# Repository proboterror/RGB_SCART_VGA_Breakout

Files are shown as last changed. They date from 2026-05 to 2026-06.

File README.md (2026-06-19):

# RGB SCART / VGA Breakout

For RGB/SCART modding JVC, SONY PVM video monitors and consumer CRT TVs.

Mounting holes step 10 mm, matching JVC monitors case.

Continuation of [RGB SCART Breakout board](https://github.com/proboterror/RGB_SCART_Breakout).

Features:
- SCART / VGA inputs are not switchable. Simultaneous connection are NOT RECOMMENDED, use at own risk.
- Protection diodes on SCART Blanking / VGA +5V inputs against back current with 2 devices connected.
- Sync 75 Ohm load bypass option.
- 3.5 mm mini jack connector for SCART input.

## Schematics:<br>
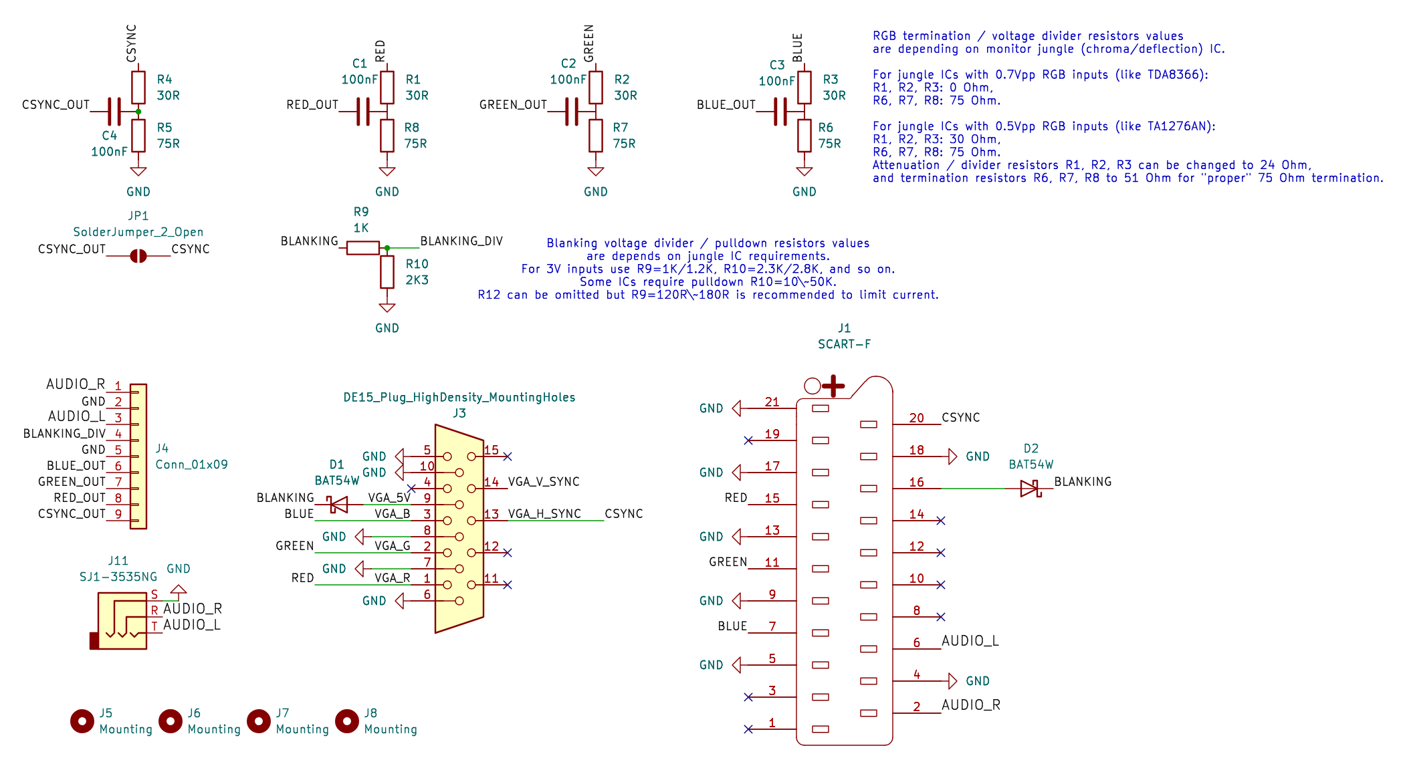
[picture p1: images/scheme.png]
Scheme


## Board view:<br>
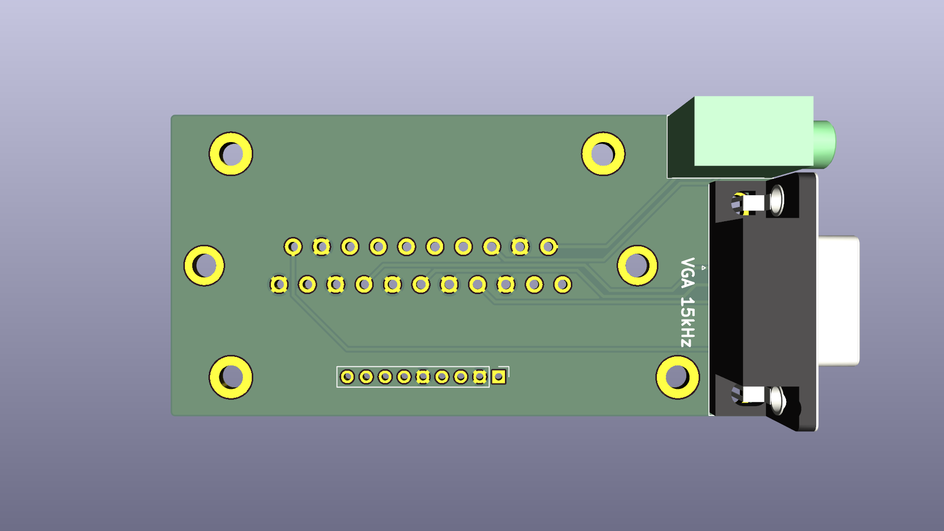
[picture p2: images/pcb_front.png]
Front

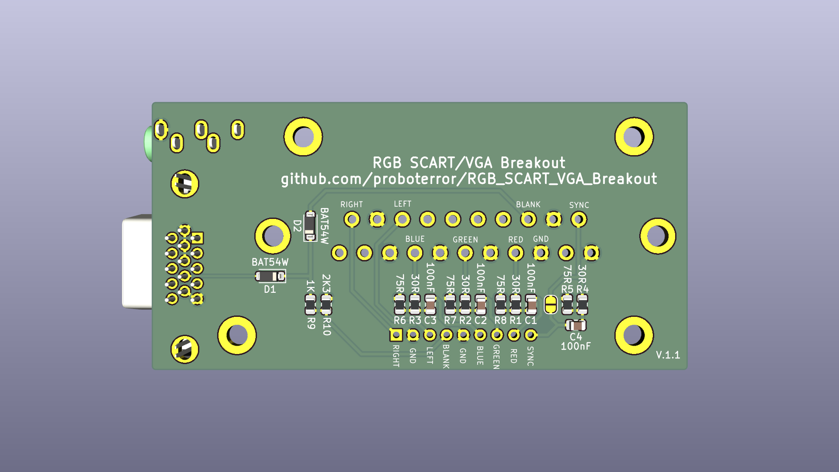
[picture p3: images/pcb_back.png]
Back

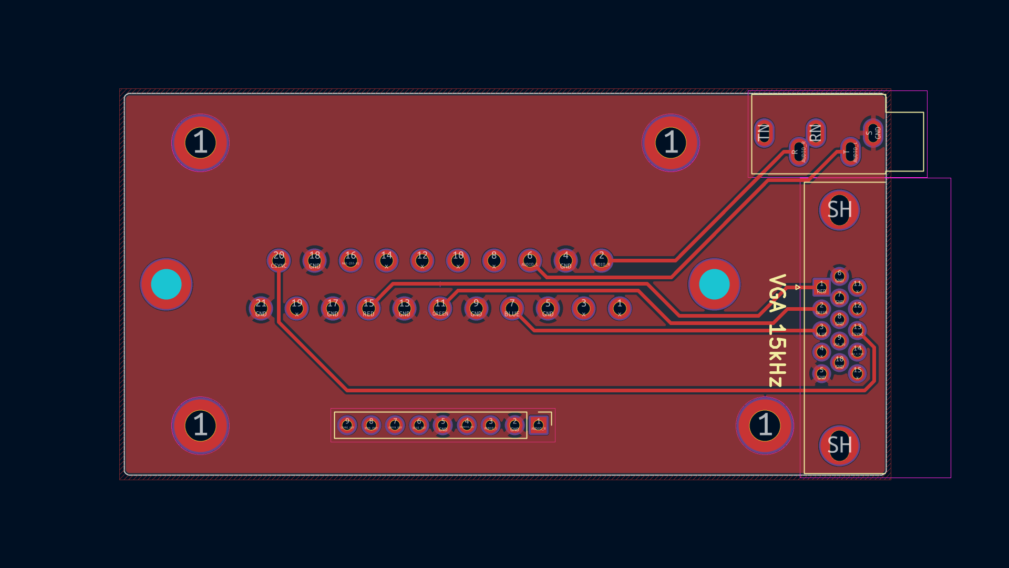
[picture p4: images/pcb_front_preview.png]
Front preview

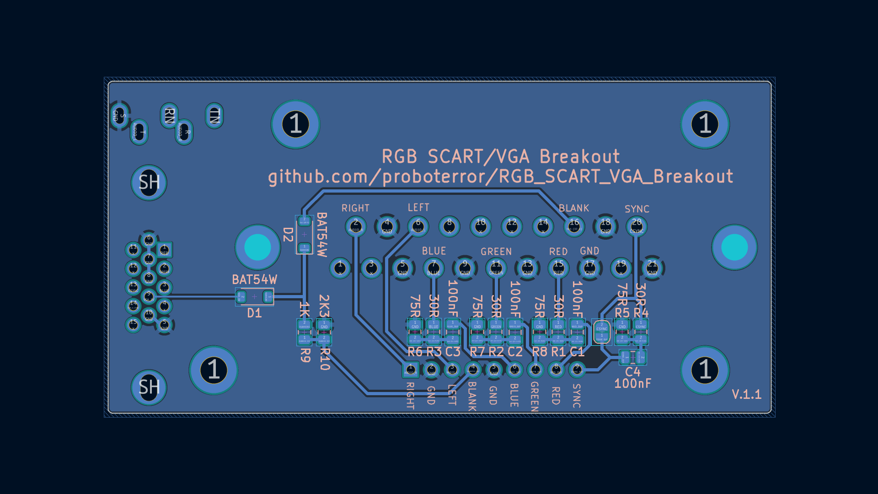
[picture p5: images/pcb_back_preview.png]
Back preview

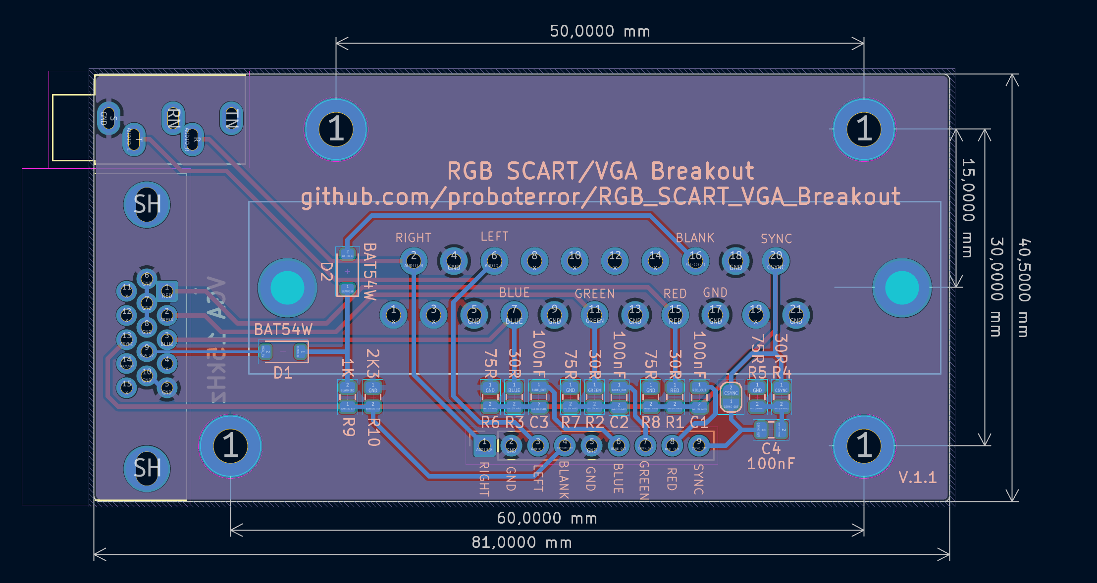
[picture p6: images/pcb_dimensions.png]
PCB dimensions


## Bill of Materials
|Reference|Value|Footprint|Qty|
|-----|-----|-----|-----|
|C1,C2,C3,C4|100nF|0805|4|
|D1,D2|BAT54W|Diode_SMD:D_SOD-123|2|
|J1|SCART-F|CS-102 (SCART-21S)|1|
|J3|DE15 Socket / DSUB-15-HD / VGA| DSUB-15-HD_Socket_Horizontal P2.29x1.90mm EdgePinOffset3.03mm MountingHolesOffset4.94mm|1|
|J11|SJ1-3535NG|CUI/Same Sky Device SJ1-3535NG|1|
|R1,R2,R3,R4|0R/24R/30R|0805|4|
|R5,R6,R7,R8|75R/51R|0805|4|
|R9|1K/1K2/4K7|0805|1|
|R10|2.3K/2K8/10K|0805|1|

Notes:
- All resistors are 1%.
- RGB termination / voltage divider resistors values are depending on monitor jungle (chroma/deflection) IC.<br>
For jungle ICs with 0.7Vpp RGB inputs (like TDA8366):<br>
R1, R2, R3: 0 Ohm,<br>
R6, R7, R8: 75 Ohm.<br>
For jungle ICs with 0.5Vpp RGB inputs (like TA1276AN):<br>
R1, R2, R3: 30 Ohm,<br>
R6, R7, R8: 75 Ohm.<br>
Attenuation / divider resistors R1, R2, R3 can be changed to 24 Ohm, and termination resistors R6, R7, R8 to 51 Ohm for "proper" 75 Ohm termination.
- Blanking voltage divider / pulldown resistors values are depends on jungle IC requirements.<br>
For 3V inputs use R9=1K/1.2K, R10=2.3K/2.8K, and so on.<br>
Some ICs require pulldown R10=10\~50K.<br>
R12 can be omitted but R9=120R\~180R is recommended to limit current.
- More info on Blanking voltage divider: [sector.sunthar.com/guides/crt-rgb-mod](https://sector.sunthar.com/guides/crt-rgb-mod/rgb-mux.html#how-to-use-the-voltage-divider-on-the-board)

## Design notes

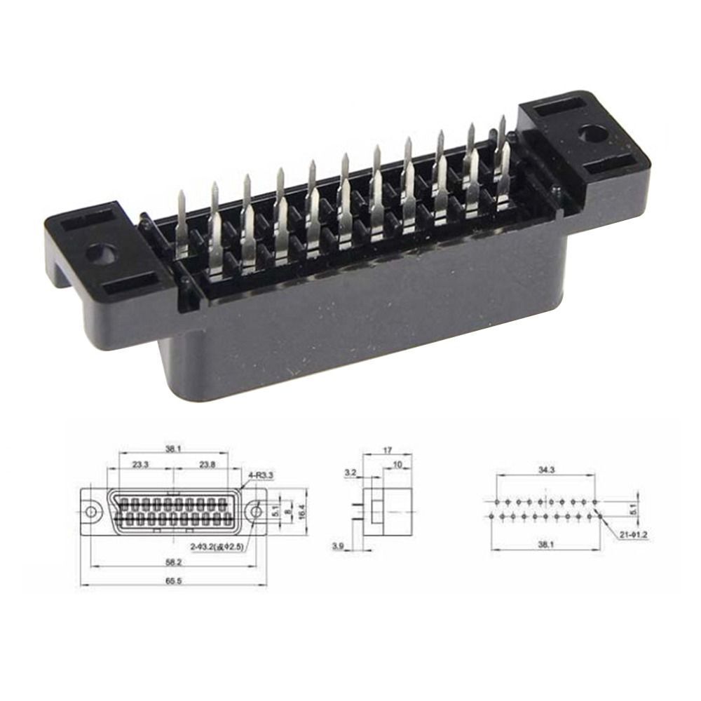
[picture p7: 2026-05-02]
datasheets/SCART_21_PIN_VERTICAL.jpg

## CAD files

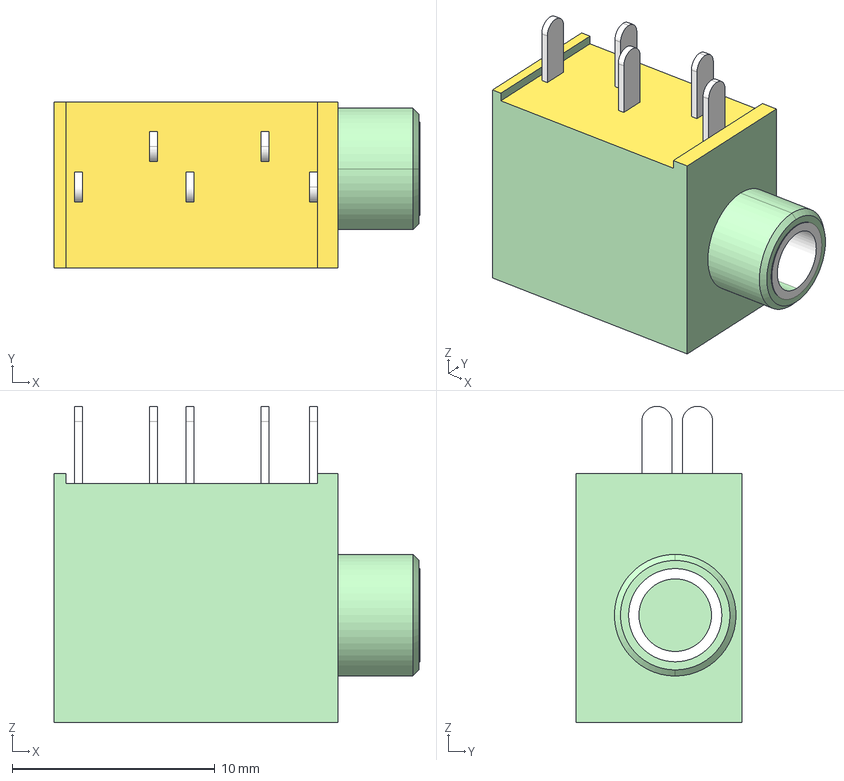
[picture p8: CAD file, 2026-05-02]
KiCad/3dshapes/CUI_DEVICES_SJ1-3535NG-G.step
18.1 x 8.20 x 15.6 mm

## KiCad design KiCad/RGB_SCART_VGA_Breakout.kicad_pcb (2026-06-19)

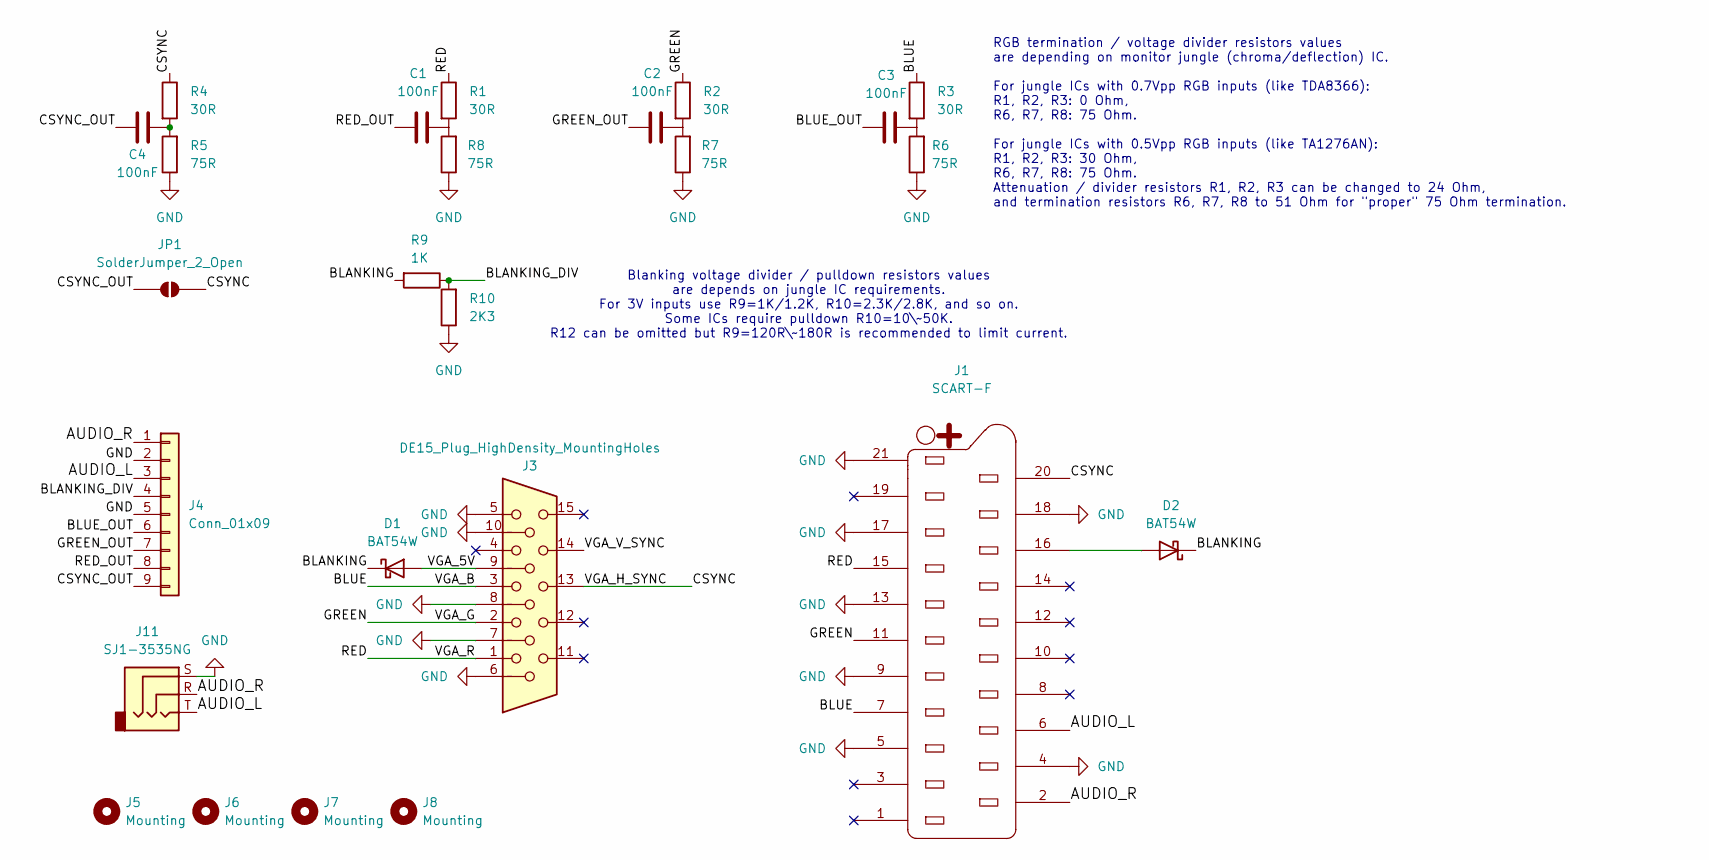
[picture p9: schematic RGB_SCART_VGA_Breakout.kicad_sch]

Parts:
C1, C2, C3, C4: 100nF; C_0805_2012Metric
D1, D2: BAT54W; D_SOD-123
J1: SCART-F; K-SCARTX-024
J3: DE15_Plug_HighDensity_MountingHoles; DSUB-15-HD_Socket_Horizontal_P2.29x1.90mm_EdgePinOffset3.03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
J4: Conn_01x09; PinHeader_1x09_P2.54mm_Vertical
J5, J6, J7, J8: Mounting; MountingHole_3.2mm_M3_DIN965_Pad
J11: SJ1-3535NG; Jack_3.5mm_CUI_SJ1-3535NG_Horizontal
JP1: SolderJumper_2_Open; SolderJumper-2_P1.3mm_Open_RoundedPad1.0x1.5mm
R1, R2, R3, R4: 30R; R_0805_2012Metric
R5, R6, R7, R8: 75R; R_0805_2012Metric
R9: 1K; R_0805_2012Metric
R10: 2K3; R_0805_2012Metric

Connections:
/AUDIO_L: J1.6, J4.3, J11.T
/AUDIO_R: J1.2, J4.1, J11.R
/BLANKING: D1.1 (K), D2.1 (K), R9.2
/BLANKING_DIV: J4.4, R9.1, R10.2
/BLUE: J1.7, J3.3, R3.1
/BLUE_OUT: C3.1, J4.6
/CSYNC: J1.20, J3.13, JP1.2 (B), R4.1
/CSYNC_OUT: C4.1, J4.9, JP1.1 (A)
/GREEN: J1.11, J3.2, R2.1
/GREEN_OUT: C2.1, J4.7
/RED: J1.15, J3.1, R1.1
/RED_OUT: C1.1, J4.8
/VGA_5V: D1.2 (A), J3.9
/VGA_V_SYNC: J3.14
GND: J1.4, J1.5, J1.9, J1.13, J1.17, J1.18, J1.21, J3.5, J3.6, J3.7, J3.8, J3.10, J4.2, J4.5, J11.S, R5.1, R6.1, R7.1, R8.1, R10.1
unnamed: C1.2, R1.2, R8.2
unnamed: C2.2, R2.2, R7.2
unnamed: C3.2, R3.2, R6.2
unnamed: C4.2, R4.2, R5.2
unnamed: D2.2 (A), J1.16

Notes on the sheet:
RGB termination / voltage divider resistors values are depending on monitor jungle (chroma/deflection) IC. For jungle ICs with 0.7Vpp RGB inputs (like TDA8366): R1, R2, R3: 0 Ohm, R6, R7, R8: 75 Ohm. For jungle ICs with 0.5Vpp RGB inputs (like TA1276AN): R1, R2, R3: 30 Ohm, R6, R7, R8: 75 Ohm. Atte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
Blanking voltage divider / pulldown resistors values are depends on jungle IC requirements. For 3V inputs use R9=1K/1.2K, R10=2.3K/2.8K, and so on. Some ICs require pulldown R10=10\~50K. R12 can be omitted but R9=120R\~180R is recommended to limit current.

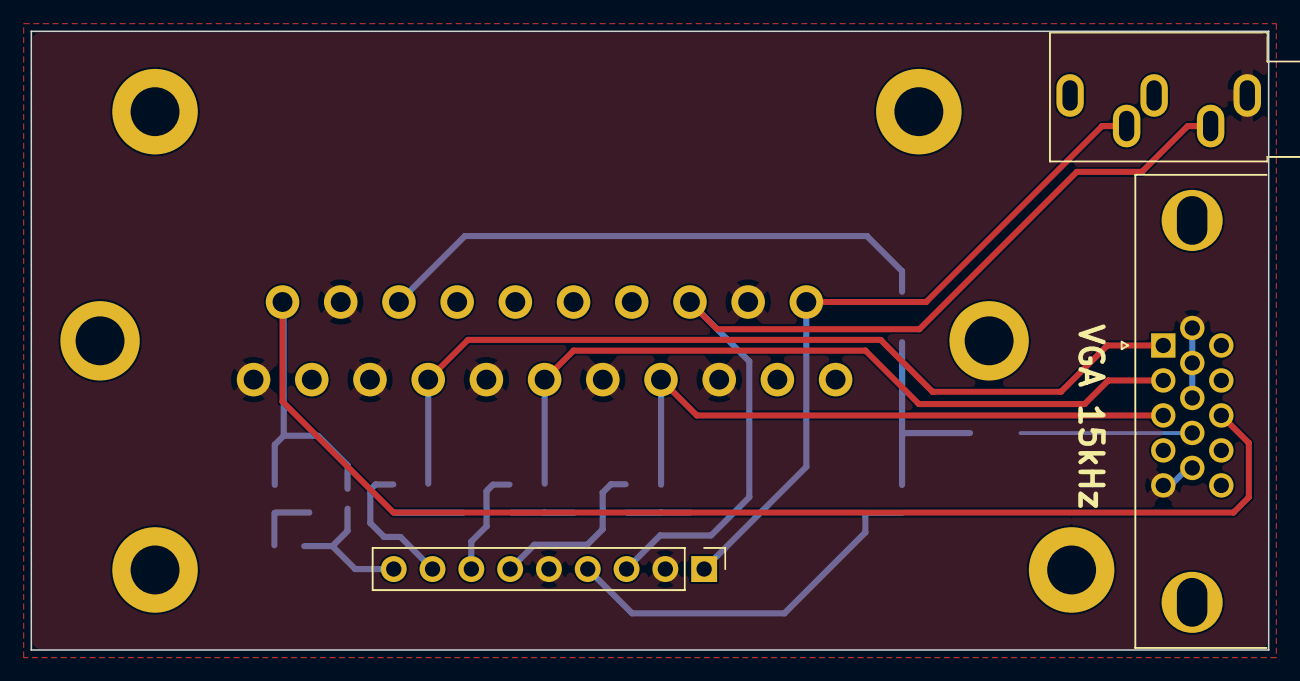
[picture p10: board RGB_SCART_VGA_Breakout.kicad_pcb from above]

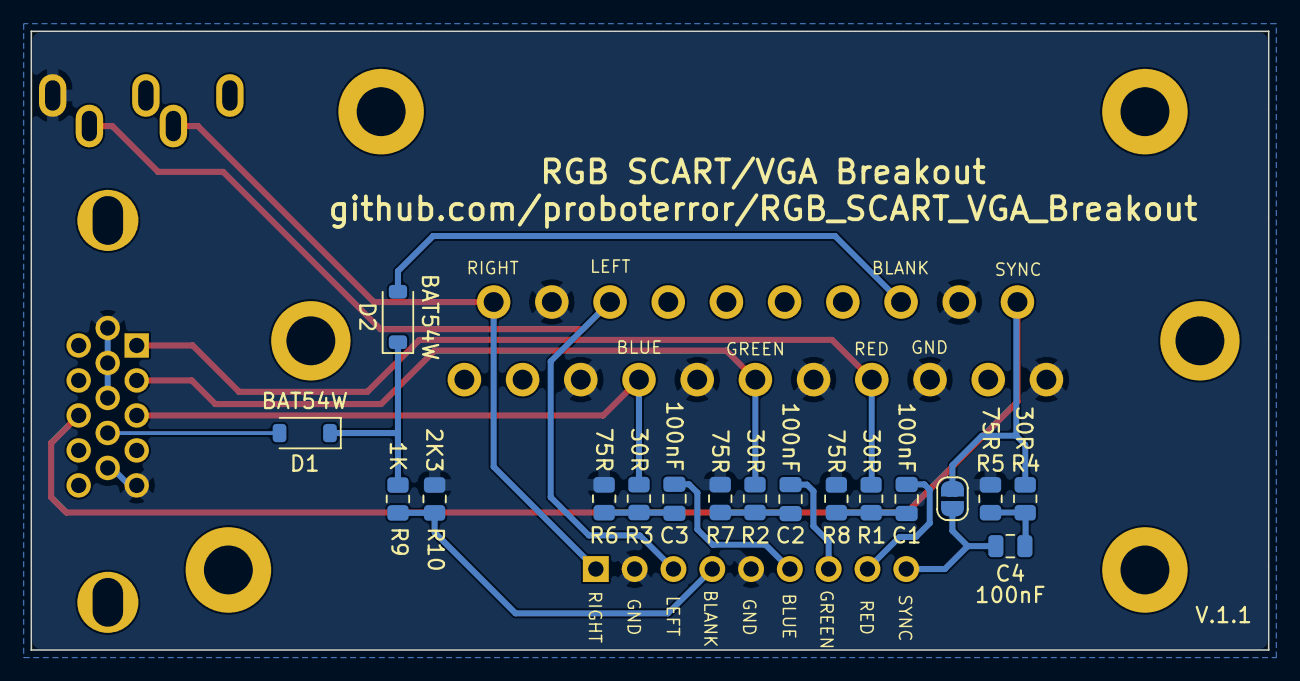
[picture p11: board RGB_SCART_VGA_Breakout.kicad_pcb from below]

Board: 2 copper layers, 81.0 x 40.5 mm, 25 parts (17 on the bottom side), 19 nets.

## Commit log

2026-05-02 Initial implementation.
    [CUI_DEVICES_SJ1-3535NG-G.step, RGB_SCART_VGA_Breakout.kicad_pcb, RGB_SCART_VGA_Breakout.kicad_sch]
2026-05-27 Fixed DE15/VGA connector pinout.
    [RGB_SCART_VGA_Breakout.kicad_pcb, RGB_SCART_VGA_Breakout.kicad_sch]
2026-06-19 Added blanking voltage divider / pulldown resistors with description. Expanded RGB load / voltage divider resistors description. VGA pins 7,8,10 connected to GND.
    PCB version 1.1.
    [RGB_SCART_VGA_Breakout.kicad_pcb, RGB_SCART_VGA_Breakout.kicad_sch]
